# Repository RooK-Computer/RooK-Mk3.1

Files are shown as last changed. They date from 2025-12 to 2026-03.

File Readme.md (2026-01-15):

# RooK Mk3.1

RooK is a retro gaming console based on the Raspberry PI CM4/CM5. It has all the peripherials you need to be used as an old (modernish) console:

* HDMI for audio and video out.
* Barrel jack for 5V power input, because we love the simplicity of barrel jacks.
* an audio jack for, well... speakers!
* 4 USB ports for up to 4 modern gamepads.
* A cartridge slot!
* 3 Buttons to shut RooK down, exit the game and restart the game.

## How it all works

It's quite simple: instead of having an onboard SD card, the SD cards are installed onto separate PCBs for the cartridges. Once you put a cartridge in, RooK powers up and boots off the SD card in the cartridge.

Of course, unwrapping the SD cards can be tedious, so we built a cartridge reader.

It works out of the box with retropie, except for the three buttons. In this repository you find the software needed to enable those buttons. It's best done immediately after installing retropie, before you customize your setup.

## In this repository

There are 3 folders:

* software contains the sources for the .deb file to easily install overwatch and it's configuration. You'll find the .dep file in there as well, if you don't want to build it yourself. The source is compressed, as we have to ensure ownership and file privileges. Something git tends to ignore ;)
* PCBs contains all the designs for the PCBs involved: 
    * Cartridge - the PCB for cartridges
    * CartridgeReader - should be self-explanatory
    * KeyswitchCarrier - holds the switches for the three keys
    * Mainboard - the biggest of them.
    * Parts and CM4-Files are referenced in the aforementioned design files
* STLs contain the STL files for the case and the cartridge. You'll find our FreeCAD designs in there as well.

## I wanna build one!

Well for now, you have to produce and order the parts yourself. We're working on this. Stay tuned and keep an eye out at [rook.computer](https://rook.computer).

There is a building guide in the wiki.

## License

Unless noted otherwise this work is licensed under Creative Commons Attribution Share Alike 4.0 International.

`SPDX-License-Identifier:  CC-BY-SA-4.0`

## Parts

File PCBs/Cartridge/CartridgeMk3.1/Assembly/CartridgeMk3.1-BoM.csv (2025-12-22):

Id | Designator | Footprint | Quantity | Designation | Supplier and ref
2 | R1,R3,R5,R2,R4 | R_0201_0603Metric | 5 | 10k
3 | J2 | SDCARD_MOLEX_503398-1892 | 1 | Micro_SD_Card

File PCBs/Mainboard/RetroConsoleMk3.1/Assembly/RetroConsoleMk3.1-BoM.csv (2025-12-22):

Id | Designator | Footprint | Quantity | Designation | Supplier and ref
1 | R13,R12,R15,R11,R14,R16 | R_0201_0603Metric | 6 | 33
3 | C3 | C_0201_0603Metric | 1 | 10nF
4 | J7,J5,J6,J3 | USB_A_Molex_67643_Horizontal | 4 | USB_A | https://www.molex.com/en-us/products/part-detail/676432911
5 | C7,C5 | C_1206_3216Metric | 2 | 47uF
6 | J10 | SJ335083BTR | 1 | SJ3-35083B-TR | https://www.mouser.de/ProductDetail/Same-Sky/SJ3-35083B-TR?qs=IKkN%2F947nfDjNSxAQdYIVA%3D%3D
7 | J16,J15 | DF40C100DS04V51 | 2 | DF40C100DS04V51 | https://www.hirose.com/product/p/CL0684-4033-4-51?lang=en#
8 | J8 | PJ114AHSMTTR | 1 | PJ-114AH-SMT-TR | https://www.mouser.de/ProductDetail/Same-Sky/PJ-114AH-SMT-TR
9 | R7,R4 | R_0201_0603Metric | 2 | 220
10 | Y1 | 830108208209 | 1 | 830108208209 | https://www.mouser.de/ProductDetail/Wurth-Elektronik/830108208209?qs=hWgE7mdIu5Qfk68EXTEoAw%3D%3D
11 | R1 | R_0201_0603Metric | 1 | 1k
13 | R5,R8 | R_0201_0603Metric | 2 | 100
14 | IC2 | SOT65P210X110-6N | 1 | NC7WZ16P6X | https://www.mouser.de/ProductDetail/onsemi-Fairchild/NC7WZ16P6X?qs=yRUxxYa83cgjitXtxHB4eA%3D%3D
15 | R6,R9 | R_0201_0603Metric | 2 | 1.8k
17 | D1 | LED_0201_0603Metric | 1 | GREEN
18 | C6,C4 | C_0201_0603Metric | 2 | 100nF
20 | R10 | R_0201_0603Metric | 1 | 10k
21 | C1,C2 | C_0201_0603Metric | 2 | 14pF
23 | J9 | 18710581 | 1 | 1871058-1 | https://www.mouser.de/ProductDetail/TE-Connectivity/1871058-1?qs=%252BoxYCnKeKt%252BrW4wNNMzC1A%3D%3D
24 | J4 | HDMI_A_Molex_208658-1001_Horizontal | 1 | HDMI_A_1.4
25 | Q1 | IRF2804STRLPBF | 1 | IRLZ34NSTRLPBF | https://www.mouser.de/ProductDetail/Infineon-Technologies/IRLZ34NSTRLPBF?qs=9%252BKlkBgLFf3%2F7oYCM5eA2g%3D%3D
26 | J14 | JST_PH_B4B-PH-K_1x04_P2.00mm_Vertical | 1 | Keys
28 | J1 | JST_SH_BM04B-SRSS-TB_1x04-1MP_P1.00mm_Vertical | 1 | Conn_01x04_Socket
29 | R2 | R_0201_0603Metric | 1 | 100k
30 | R3 | R_0201_0603Metric | 1 | 12k (+/- 1%)
31 | IC1 | QFN50P600X600X100-37N-D | 1 | USB2514B_M2 | https://www.mouser.de/ProductDetail/Microchip-Technology/USB2514B-M2?qs=uus7iwvxYD9zlzrAre8ynw%3D%3D

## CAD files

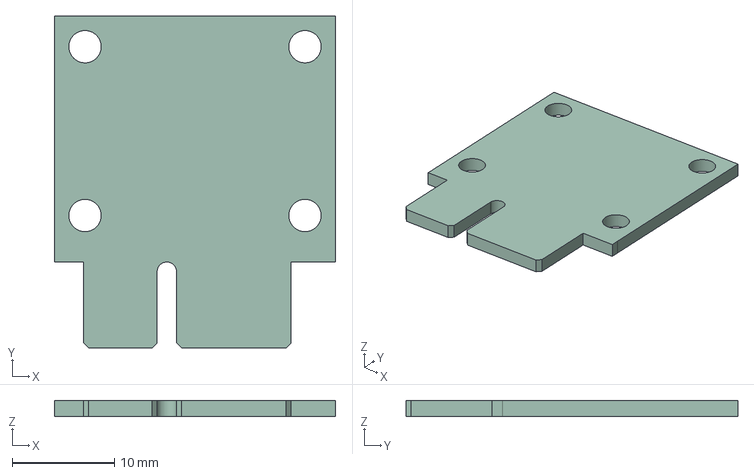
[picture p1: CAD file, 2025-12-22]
PCBs/Cartridge/CartridgeMk3.1/CartridgeMk1_simple.step
27.5 x 32.5 x 1.60 mm

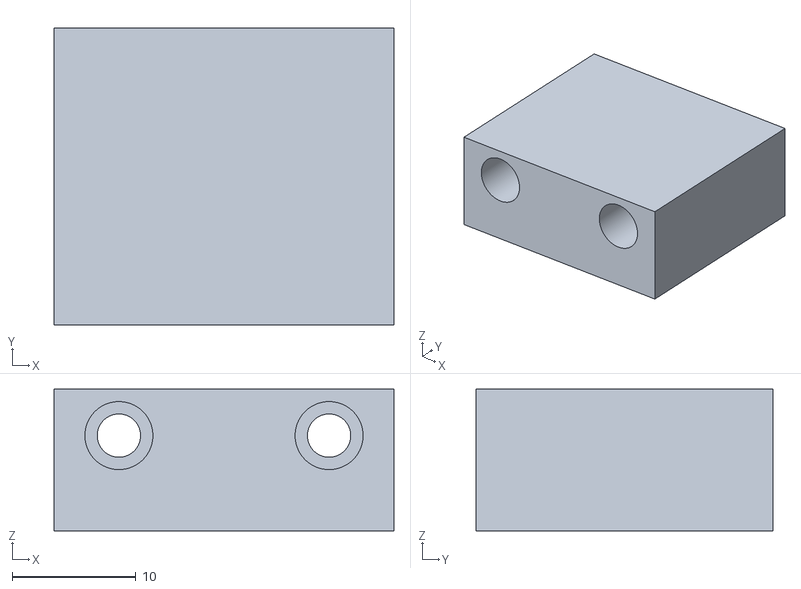
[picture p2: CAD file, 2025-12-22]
STLs/LegoInspiredCase_by_Konnexus_Mk1/CartridgeMk2-STLs/CartridgeMk3-FrontSide.stl
27.5 x 24.0 x 11.5

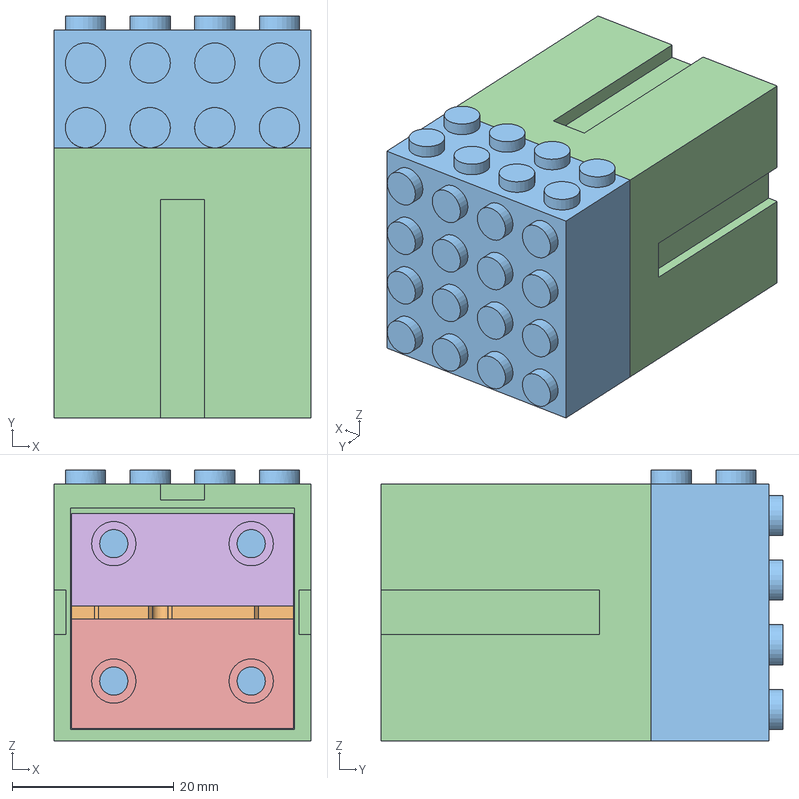
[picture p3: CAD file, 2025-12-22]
STLs/LegoInspiredCase_by_Konnexus_Mk1/CartridgeMk3.FCStd
31.8 x 49.7 x 33.5 mm
CartridgeMk1_PCB
TopPanel
Housing
BackSide
FrontSide

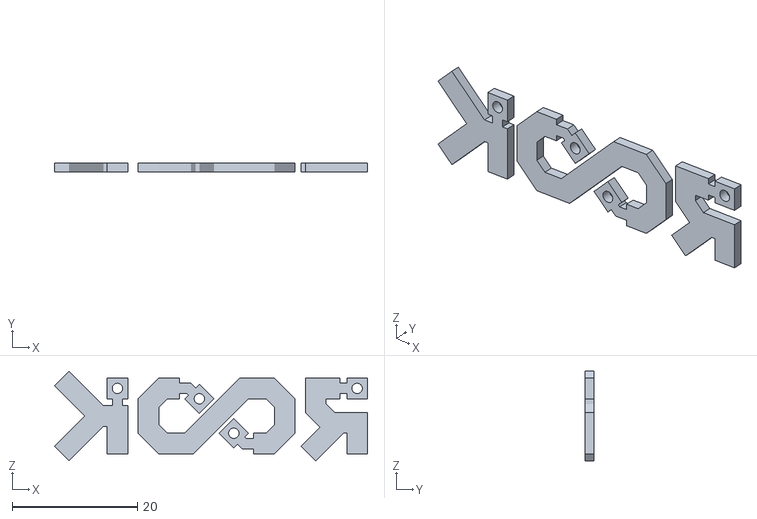
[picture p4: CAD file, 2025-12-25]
STLs/LegoInspiredCase_by_Konnexus_Mk1/Case-STLs/BackPanel_Inlay.stl
50.0 x 1.40 x 14.3

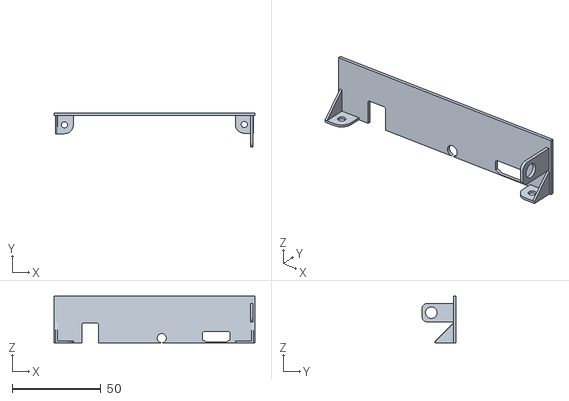
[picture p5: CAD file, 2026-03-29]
STLs/WifiAntennaMod/BackPanel_internal_antenna.stl
113.2 x 19.2 x 26.2

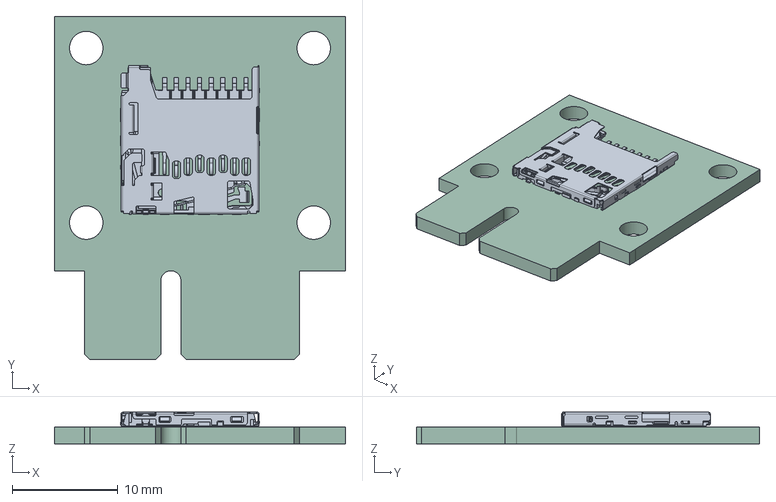
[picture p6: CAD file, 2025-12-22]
PCBs/Cartridge/CartridgeMk3.1/CartridgeMk3.1.step
27.5 x 32.5 x 2.98 mm
CartridgeMk1_PCB

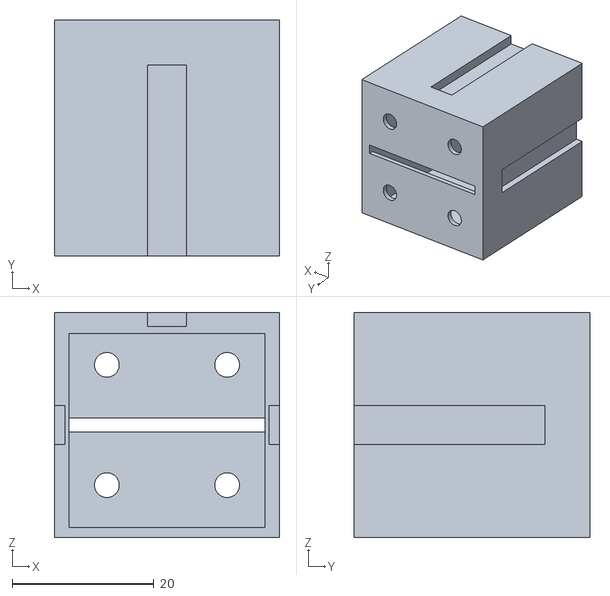
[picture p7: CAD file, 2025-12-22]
STLs/LegoInspiredCase_by_Konnexus_Mk1/CartridgeMk2-STLs/CartridgeMk3-Housing.stl
31.8 x 33.4 x 31.8

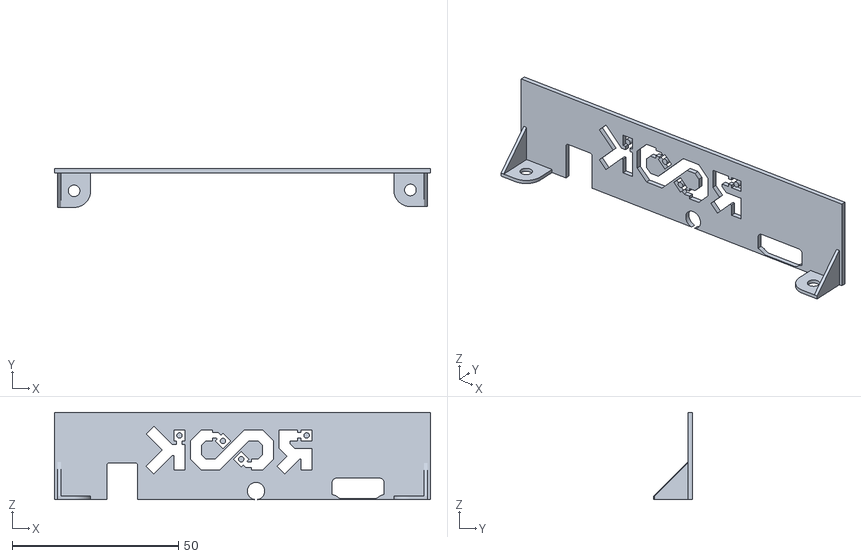
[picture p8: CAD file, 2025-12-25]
STLs/LegoInspiredCase_by_Konnexus_Mk1/Case-STLs/BackPanel.stl
113.2 x 11.7 x 26.2

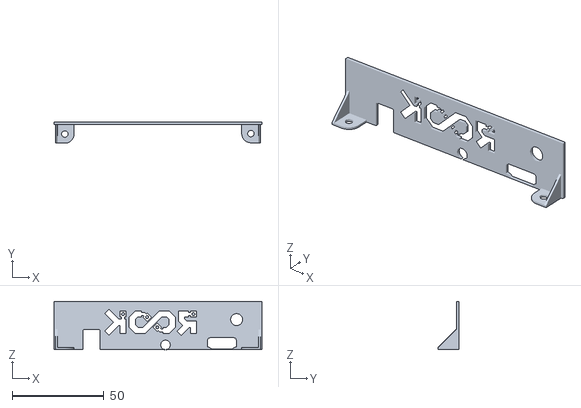
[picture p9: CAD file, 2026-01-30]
STLs/WifiAntennaMod/BackPanel.stl
113.2 x 11.7 x 26.2

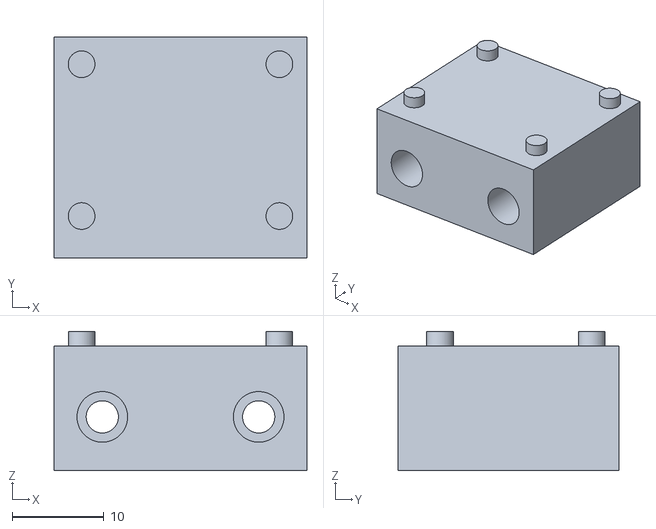
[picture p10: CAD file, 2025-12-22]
STLs/LegoInspiredCase_by_Konnexus_Mk1/CartridgeMk2-STLs/CartridgeMk3-BackSide.stl
27.5 x 24.0 x 15.2

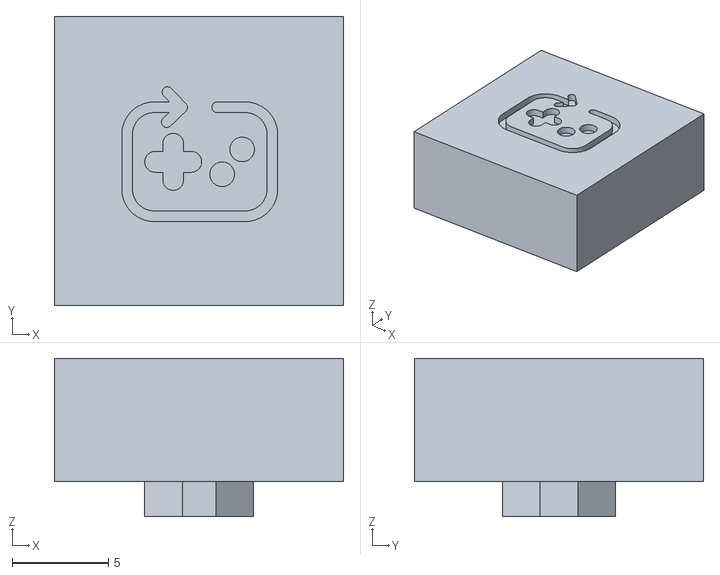
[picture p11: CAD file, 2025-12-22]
STLs/LegoInspiredCase_by_Konnexus_Mk1/Case-STLs/ResetButton_fat.stl
15.0 x 15.0 x 8.21

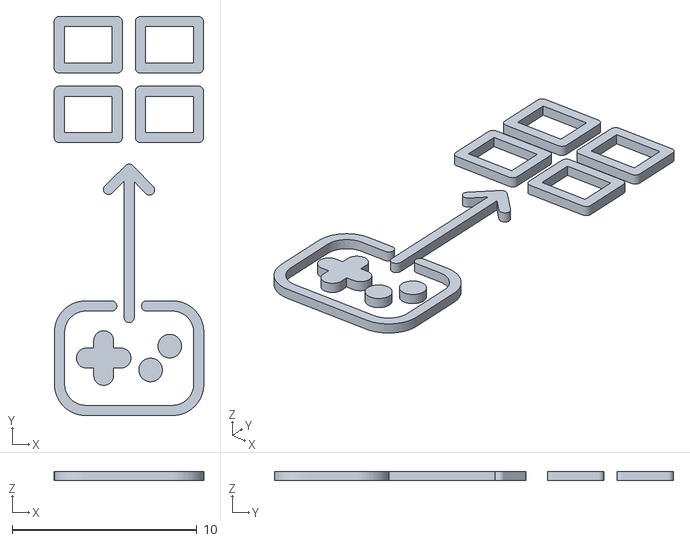
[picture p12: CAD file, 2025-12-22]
STLs/LegoInspiredCase_by_Konnexus_Mk1/Case-STLs/QuitButton_fat_print.stl
8.11 x 21.6 x 0.5

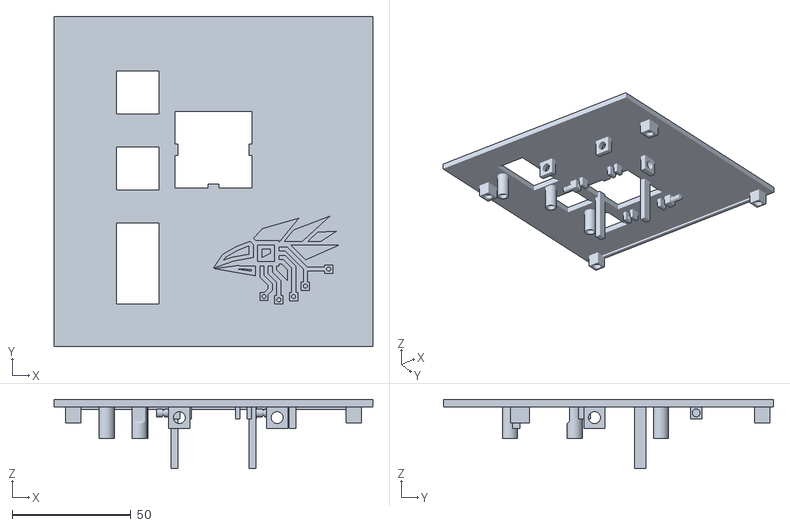
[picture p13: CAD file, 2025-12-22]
STLs/LegoInspiredCase_by_Konnexus_Mk1/Case-STLs/Cover.stl
134.2 x 139.0 x 29.2

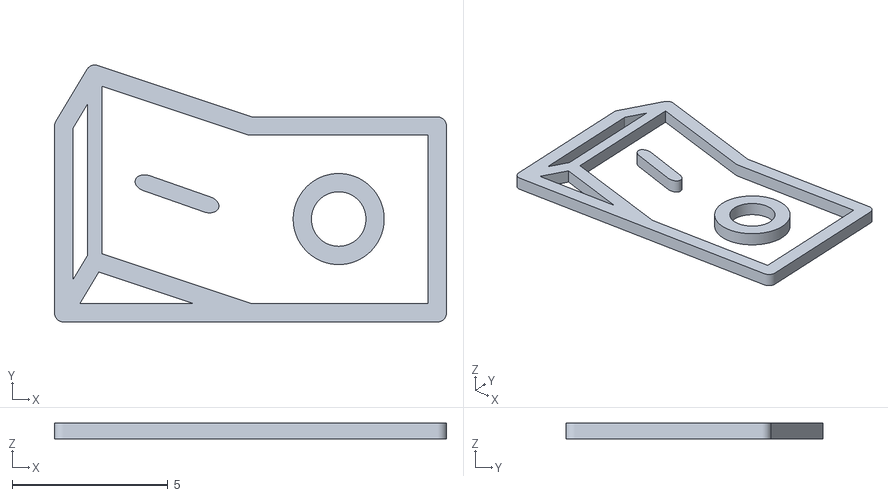
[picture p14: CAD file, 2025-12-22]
STLs/LegoInspiredCase_by_Konnexus_Mk1/Case-STLs/ShutdownButton_print.stl
12.6 x 8.24 x 0.5

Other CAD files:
STLs/LegoInspiredCase_by_Konnexus_Mk1/Case-STLs/ShutdownButton.stl
STLs/LegoInspiredCase_by_Konnexus_Mk1/Case-STLs/SlotCover.stl
STLs/LegoInspiredCase_by_Konnexus_Mk1/Case-STLs/ShutdownButton_border.stl
STLs/LegoInspiredCase_by_Konnexus_Mk1/Case-STLs/QuitButton_fat.stl
STLs/LegoInspiredCase_by_Konnexus_Mk1/Case-STLs/Base.stl
STLs/LegoInspiredCase_by_Konnexus_Mk1/Case-STLs/Pillars.stl
STLs/LegoInspiredCase_by_Konnexus_Mk1/Case-STLs/QuitButton_fat_border.stl
STLs/LegoInspiredCase_by_Konnexus_Mk1/Case-STLs/ResetButton_fat_border.stl
STLs/LegoInspiredCase_by_Konnexus_Mk1/Case-STLs/ResetButton_fat_print.stl

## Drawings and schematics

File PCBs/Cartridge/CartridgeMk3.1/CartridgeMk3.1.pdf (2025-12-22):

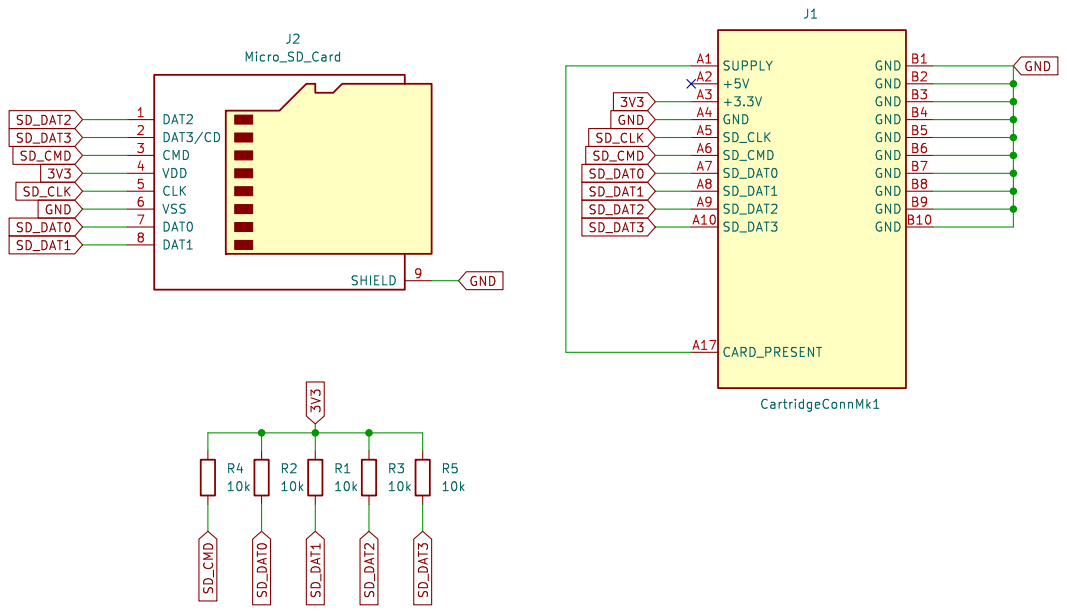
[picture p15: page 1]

Id: 1/1 Title: File: CartridgeMk3.kicad_sch Sheet: /

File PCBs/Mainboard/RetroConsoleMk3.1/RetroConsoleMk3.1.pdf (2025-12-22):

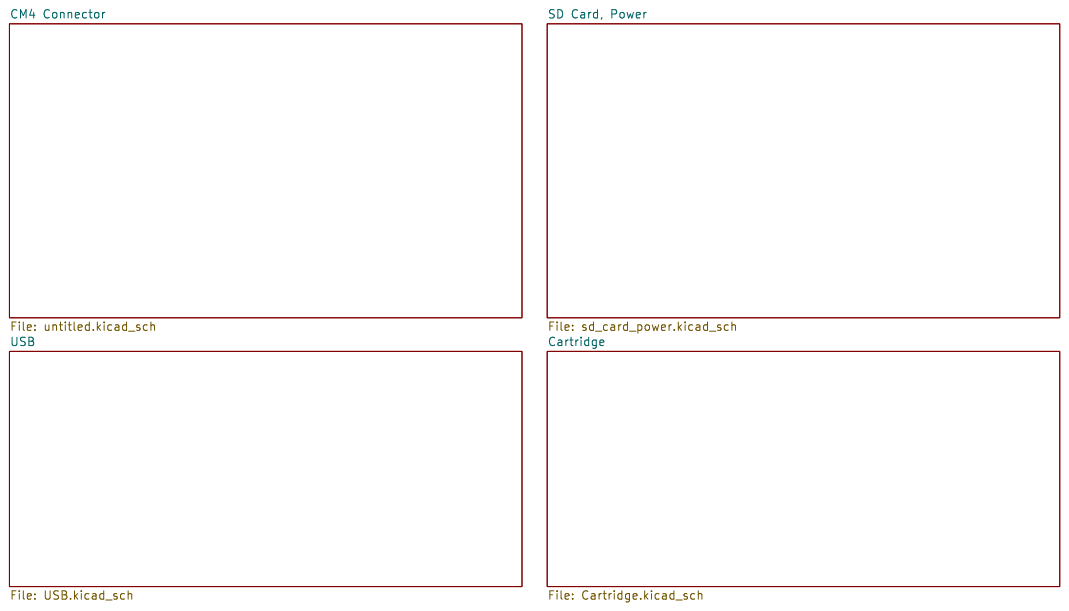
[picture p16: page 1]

File: USB.kicad_sch CM4 Connector File: untitled.kicad_sch

SD Card, Power File: sd_card_power.kicad_sch USB

Id: 1/5 Title: File: RetroConsoleMk3.kicad_sch Sheet: /

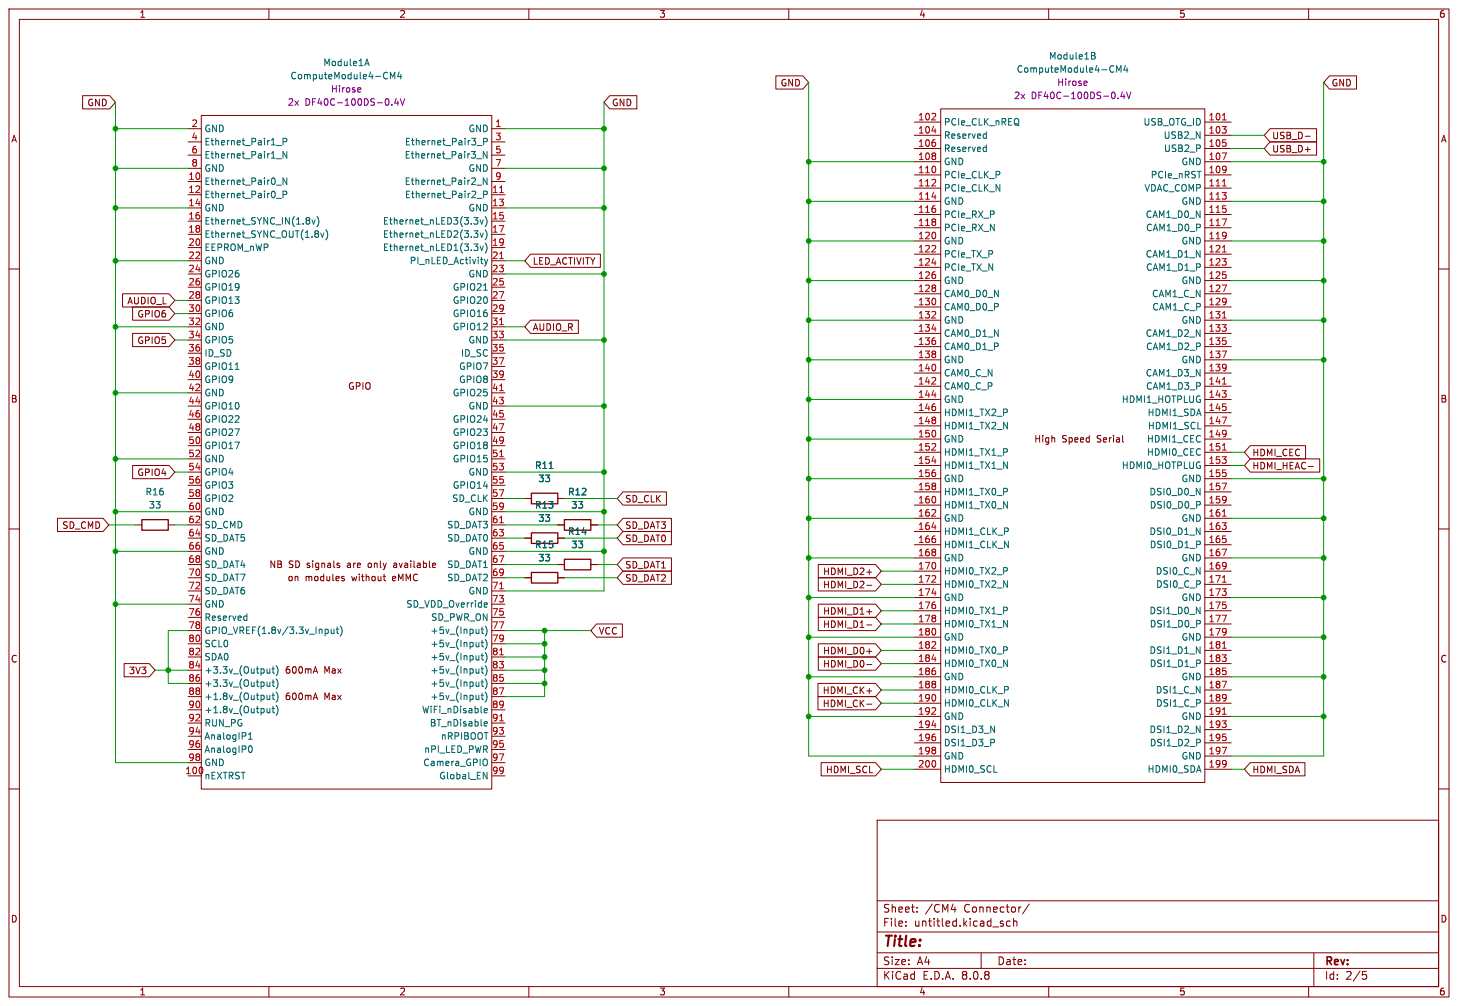
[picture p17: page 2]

600mA Max 600mA Max NB SD signals are only available

Id: 2/5 Title: File: untitled.kicad_sch Sheet: /CM4 Connector/

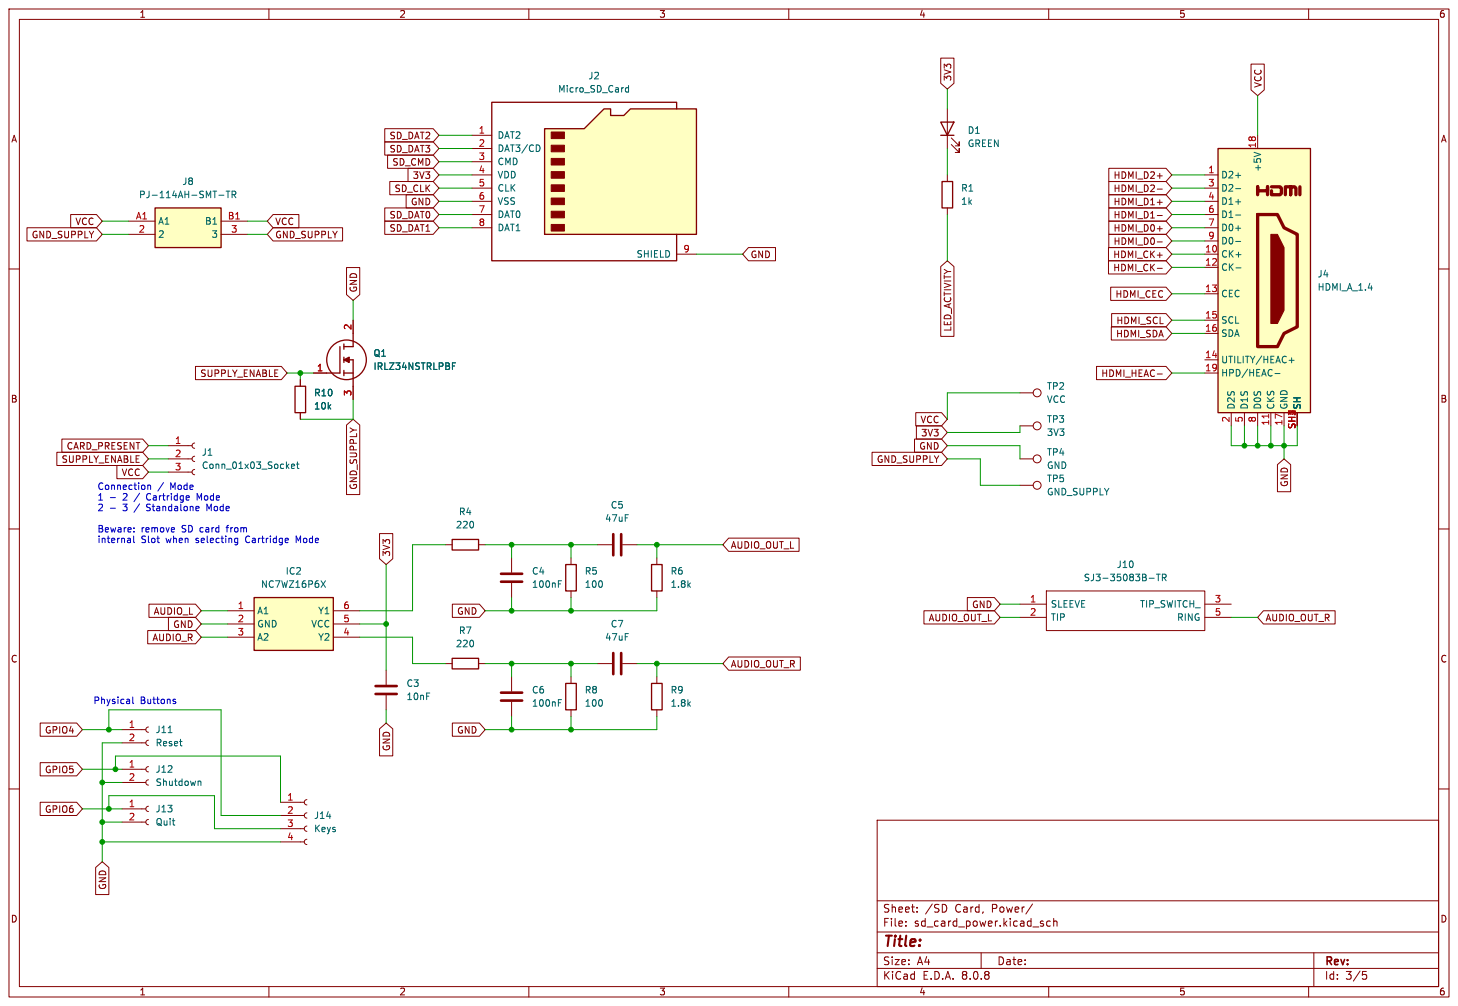
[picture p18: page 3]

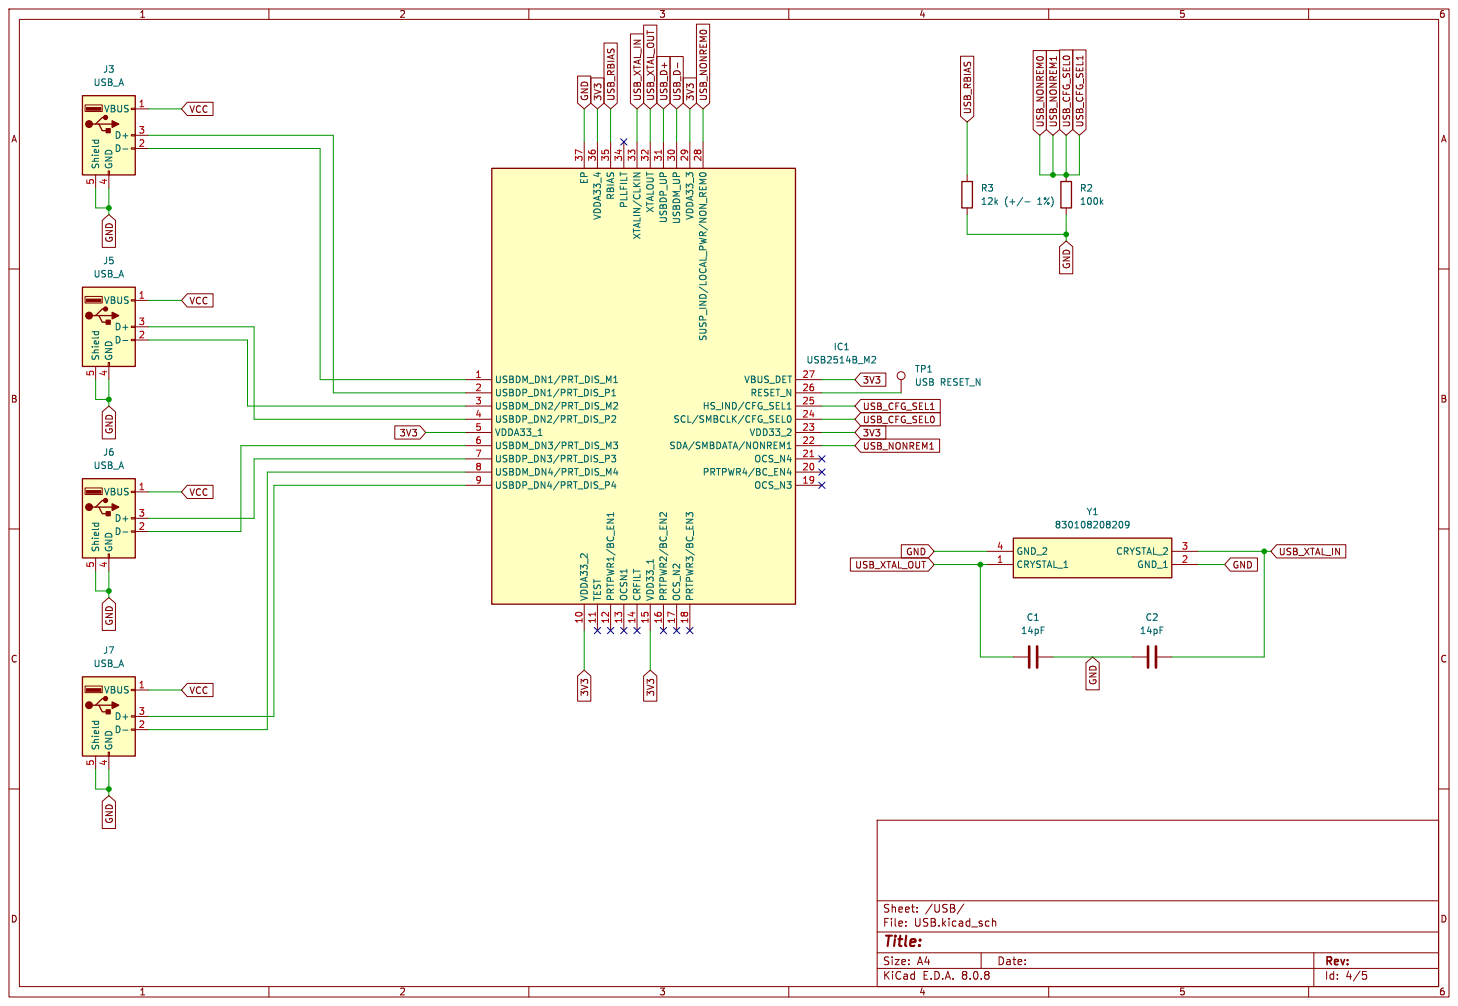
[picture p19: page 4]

Id: 4/5 Title: File: USB.kicad_sch Sheet: /USB/

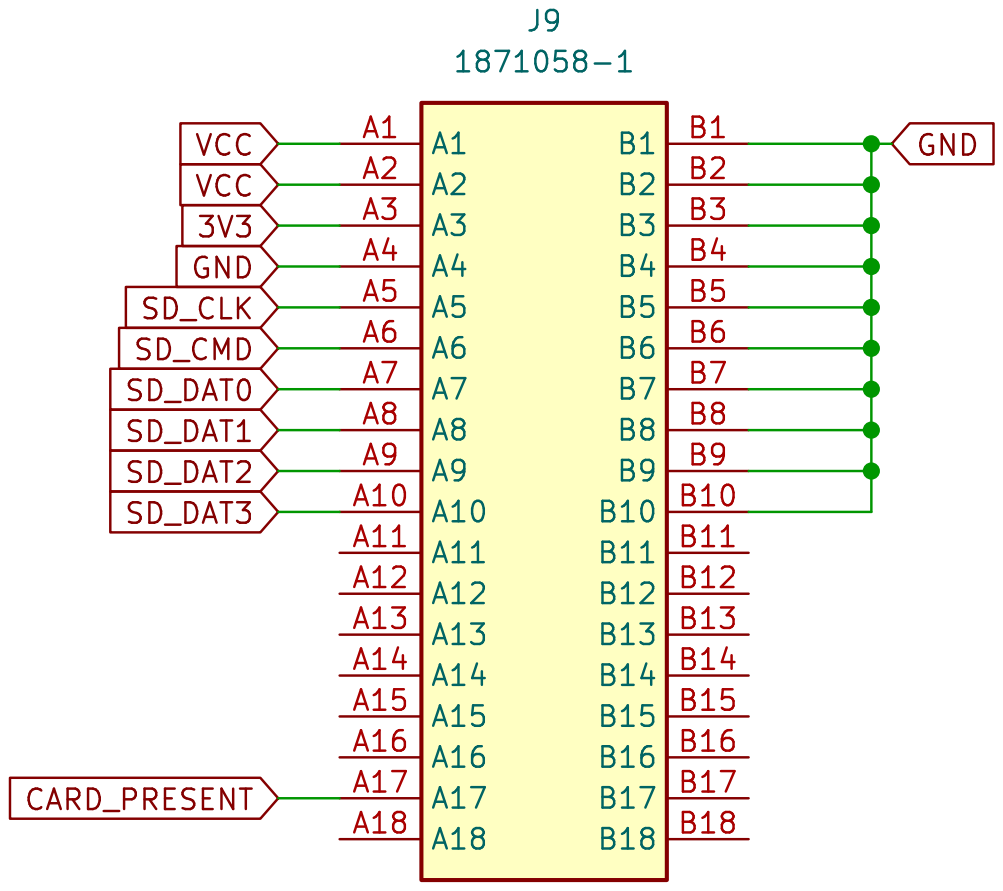
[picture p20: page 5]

Id: 5/5 Title: File: Cartridge.kicad_sch Sheet: /Cartridge/

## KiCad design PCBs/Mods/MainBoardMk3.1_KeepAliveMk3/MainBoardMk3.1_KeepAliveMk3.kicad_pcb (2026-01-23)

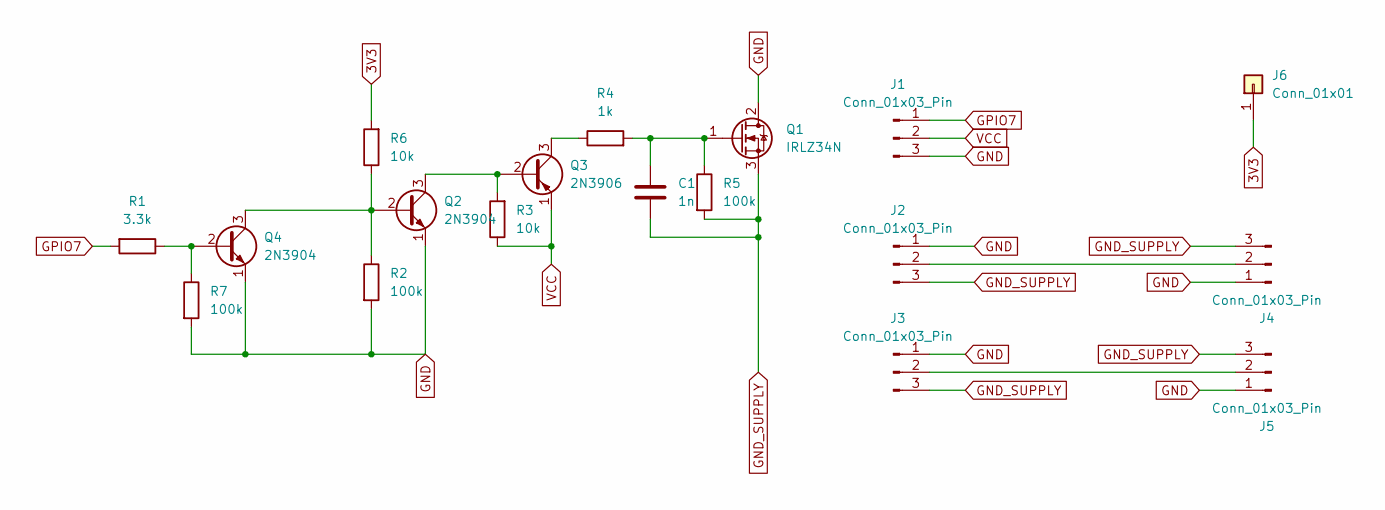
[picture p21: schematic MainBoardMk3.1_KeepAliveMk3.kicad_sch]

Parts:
C1: 1n; C_Disc_D5.0mm_W2.5mm_P2.50mm
J1, J2, J3: Conn_01x03_Pin; PinSocket_1x03_P2.54mm_Vertical
J4, J5: Conn_01x03_Pin; PinHeader_1x03_P2.54mm_Vertical
J6: Conn_01x01; SolderWire-0.5sqmm_1x01_D0.9mm_OD2.1mm
Q1: IRLZ34N; TO-220-3_Horizontal_TabDown
Q2, Q4: 2N3904; TO-92_HandSolder
Q3: 2N3906; TO-92_HandSolder
R1: 3.3k; R_Axial_DIN0207_L6.3mm_D2.5mm_P7.62mm_Horizontal
R2, R5, R7: 100k; R_Axial_DIN0207_L6.3mm_D2.5mm_P7.62mm_Horizontal
R3, R6: 10k; R_Axial_DIN0207_L6.3mm_D2.5mm_P7.62mm_Horizontal
R4: 1k; R_Axial_DIN0207_L6.3mm_D2.5mm_P7.62mm_Horizontal

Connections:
3V3: J6.1, R6.2
GND: J1.3, J2.1, J3.1, J4.1, J5.1, Q1.2 (D), Q2.1 (E), Q4.1 (E), R2.2, R7.2
GND_SUPPLY: C1.2, J2.3, J3.3, J4.3, J5.3, Q1.3 (S), R5.2
GPIO7: J1.1, R1.2
unnamed: J2.2, J4.2
unnamed: J3.2, J5.2
unnamed: C1.1, Q1.1 (G), R4.2, R5.1
unnamed: Q2.2 (B), Q4.3 (C), R2.1, R6.1
unnamed: Q2.3 (C), Q3.2 (B), R3.2
unnamed: Q3.3 (C), R4.1
unnamed: Q4.2 (B), R1.1, R7.1
VCC: J1.2, Q3.1 (E), R3.1

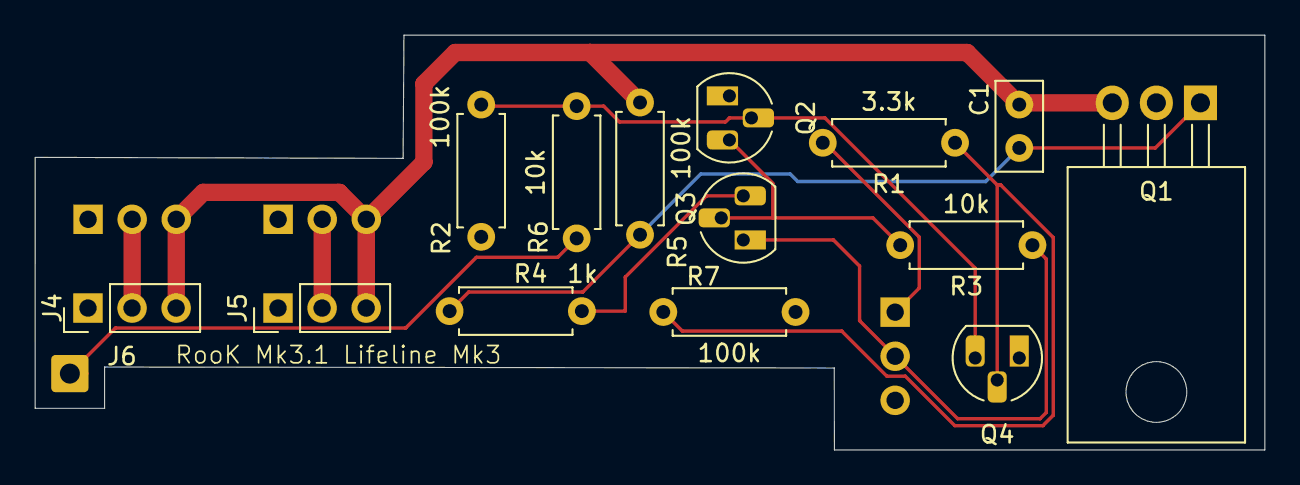
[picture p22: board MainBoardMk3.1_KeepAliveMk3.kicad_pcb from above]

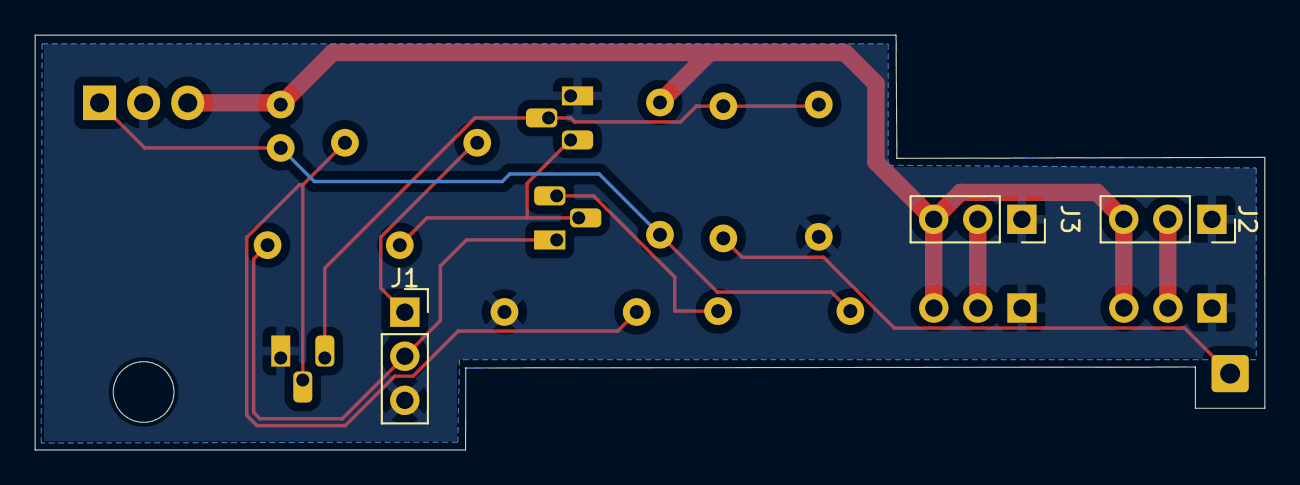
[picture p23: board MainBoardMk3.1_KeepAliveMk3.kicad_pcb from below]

Board: 2 copper layers, 70.8 x 23.9 mm, 18 parts (3 on the bottom side), 12 nets.

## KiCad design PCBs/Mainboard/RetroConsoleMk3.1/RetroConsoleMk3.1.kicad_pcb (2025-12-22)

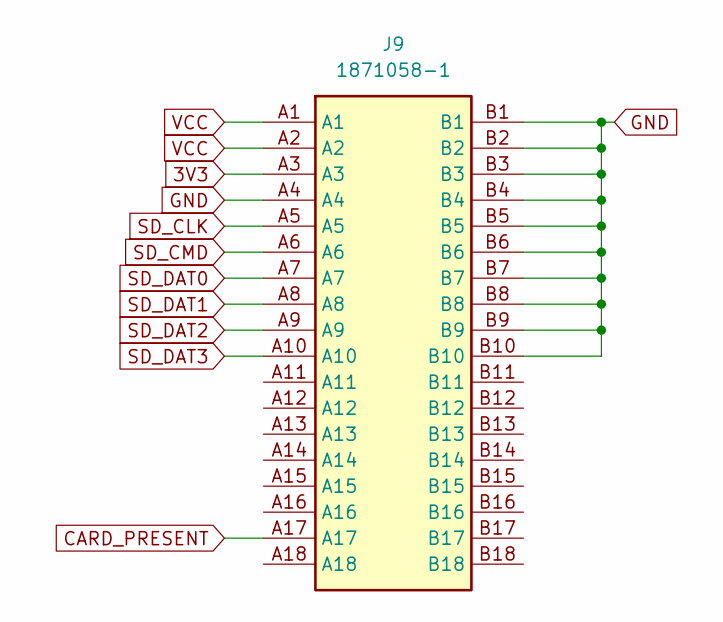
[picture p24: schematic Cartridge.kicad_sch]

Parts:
J9: 1871058-1; 18710581; Manufacturer_Part_Number 1871058-1; Mouser Part Number 571-1871058-1

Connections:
3V3: J9.A3; also elsewhere on the board
CARD_PRESENT: J9.A17; also elsewhere on the board
GND: J9.A4, J9.B1, J9.B2, J9.B3, J9.B4, J9.B5, J9.B6, J9.B7, J9.B8, J9.B9, J9.B10; also elsewhere on the board
SD_CLK: J9.A5; also elsewhere on the board
SD_CMD: J9.A6; also elsewhere on the board
SD_DAT0: J9.A7; also elsewhere on the board
SD_DAT1: J9.A8; also elsewhere on the board
SD_DAT2: J9.A9; also elsewhere on the board
SD_DAT3: J9.A10; also elsewhere on the board
VCC: J9.A1, J9.A2; also elsewhere on the board

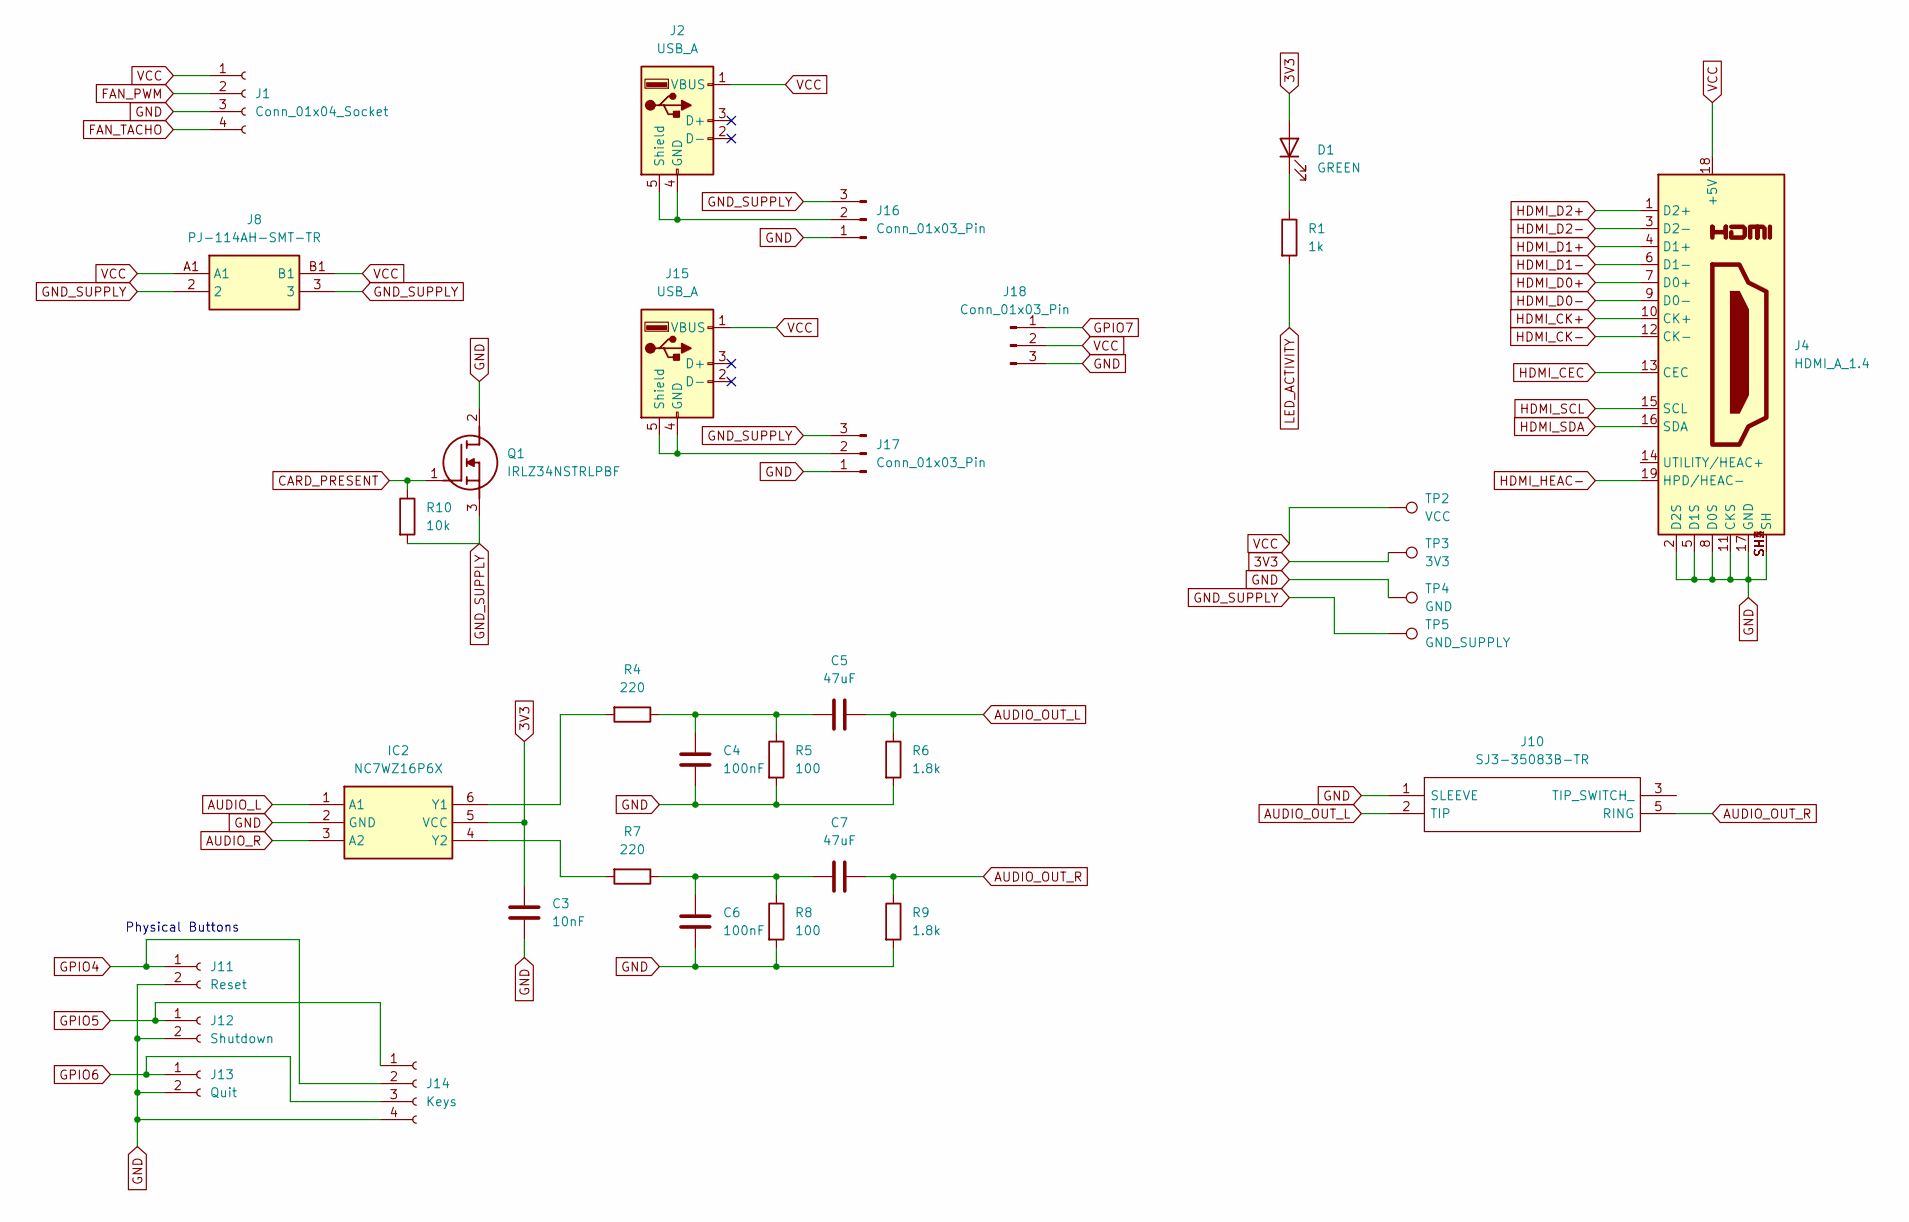
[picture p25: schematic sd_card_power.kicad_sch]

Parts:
C3: 10nF; C_0201_0603Metric
C4, C6: 100nF; C_0201_0603Metric
C5, C7: 47uF; C_1206_3216Metric
D1: GREEN; LED_0201_0603Metric
IC2: NC7WZ16P6X; SOT65P210X110-6N; Manufacturer_Part_Number NC7WZ16P6X; Mouser Part Number 512-NC7WZ16P6X
J1: Conn_01x04_Socket; JST_SH_BM04B-SRSS-TB_1x04-1MP_P1.00mm_Vertical
J2, J15: USB_A; USB_A_Wuerth_614004134726_Horizontal
J4: HDMI_A_1.4; HDMI_A_Molex_208658-1001_Horizontal
J8: PJ-114AH-SMT-TR; PJ114AHSMTTR; Manufacturer_Part_Number PJ-114AH-SMT-TR; Mouser Part Number 179-PJ-114AH-SMT-TR
J10: SJ3-35083B-TR; SJ335083BTR; Manufacturer_Part_Number SJ3-35083B-TR; Mouser Part Number 179-SJ3-35083B-TR
J11: Reset; JST_PH_B2B-PH-K_1x02_P2.00mm_Vertical
J12: Shutdown; JST_PH_B2B-PH-K_1x02_P2.00mm_Vertical
J13: Quit; JST_PH_B2B-PH-K_1x02_P2.00mm_Vertical
J14: Keys; JST_PH_B4B-PH-K_1x04_P2.00mm_Vertical
J16, J17, J18: Conn_01x03_Pin; PinHeader_1x03_P2.54mm_Vertical
Q1: IRLZ34NSTRLPBF; IRF2804STRLPBF; Manufacturer_Part_Number IRLZ34NSTRLPBF; Mouser Part Number 942-IRLZ34NSTRLPBF
R1: 1k; R_0201_0603Metric
R4, R7: 220; R_0201_0603Metric
R5, R8: 100; R_0201_0603Metric
R6, R9: 1.8k; R_0201_0603Metric
R10: 10k; R_0201_0603Metric
TP2: VCC; TestPoint_Pad_D3.0mm
TP3: 3V3; TestPoint_Pad_D3.0mm
TP4: GND; TestPoint_Pad_D3.0mm
TP5: GND_SUPPLY; TestPoint_Pad_D3.0mm

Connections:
3V3: C3.1, D1.2 (A), IC2.5 (VCC), TP3.1; also elsewhere on the board
AUDIO_L: IC2.1 (A1); also elsewhere on the board
AUDIO_OUT_L: C5.1, J10.2 (TIP), R6.1
AUDIO_OUT_R: C7.1, J10.5 (RING), R9.1
AUDIO_R: IC2.3 (A2); also elsewhere on the board
CARD_PRESENT: Q1.1 (G), R10.1; also elsewhere on the board
FAN_PWM: J1.2; also elsewhere on the board
FAN_TACHO: J1.4; also elsewhere on the board
GND: C3.2, C4.2, C6.2, IC2.2 (GND), J1.3, J4.2 (D2S), J4.5 (D1S), J4.8 (D0S), J4.11 (CKS), J4.17 (GND), J4.SH1 (SH), J4.SH2 (SH), J4.SH3 (SH), J4.SH4 (SH), J10.1 (SLEEVE), J11.2, J12.2, J13.2, J14.4, J16.1, J17.1, J18.3, Q1.2 (D), R5.2, R6.2, R8.2, R9.2, TP4.1; also elsewhere on the board
GND_SUPPLY: J8.2, J8.3, J16.3, J17.3, Q1.3 (S), R10.2, TP5.1
GPIO4: J11.1, J14.2; also elsewhere on the board
GPIO5: J12.1, J14.1; also elsewhere on the board
GPIO6: J13.1, J14.3; also elsewhere on the board
GPIO7: J18.1; also elsewhere on the board
HDMI_CEC: J4.13 (CEC); also elsewhere on the board
HDMI_CK+: J4.10 (CK+); also elsewhere on the board
HDMI_CK-: J4.12 (CK-); also elsewhere on the board
HDMI_D0+: J4.7 (D0+); also elsewhere on the board
HDMI_D0-: J4.9 (D0-); also elsewhere on the board
HDMI_D1+: J4.4 (D1+); also elsewhere on the board
HDMI_D1-: J4.6 (D1-); also elsewhere on the board
HDMI_D2+: J4.1 (D2+); also elsewhere on the board
HDMI_D2-: J4.3 (D2-); also elsewhere on the board
HDMI_HEAC-: J4.19 (HPD/HEAC-); also elsewhere on the board
HDMI_SCL: J4.15 (SCL); also elsewhere on the board
HDMI_SDA: J4.16 (SDA); also elsewhere on the board
LED_ACTIVITY: R1.2; also elsewhere on the board
unnamed: C4.1, C5.2, R4.1, R5.1
unnamed: C6.1, C7.2, R7.1, R8.1
unnamed: D1.1 (K), R1.1
unnamed: IC2.6 (Y1), R4.2
unnamed: IC2.4 (Y2), R7.2
unnamed: J15.4 (GND), J15.5 (Shield), J17.2
unnamed: J2.4 (GND), J2.5 (Shield), J16.2
VCC: J1.1, J2.1 (VBUS), J4.18 (+5V), J8.A1, J8.B1, J15.1 (VBUS), J18.2, TP2.1; also elsewhere on the board

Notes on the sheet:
Physical Buttons

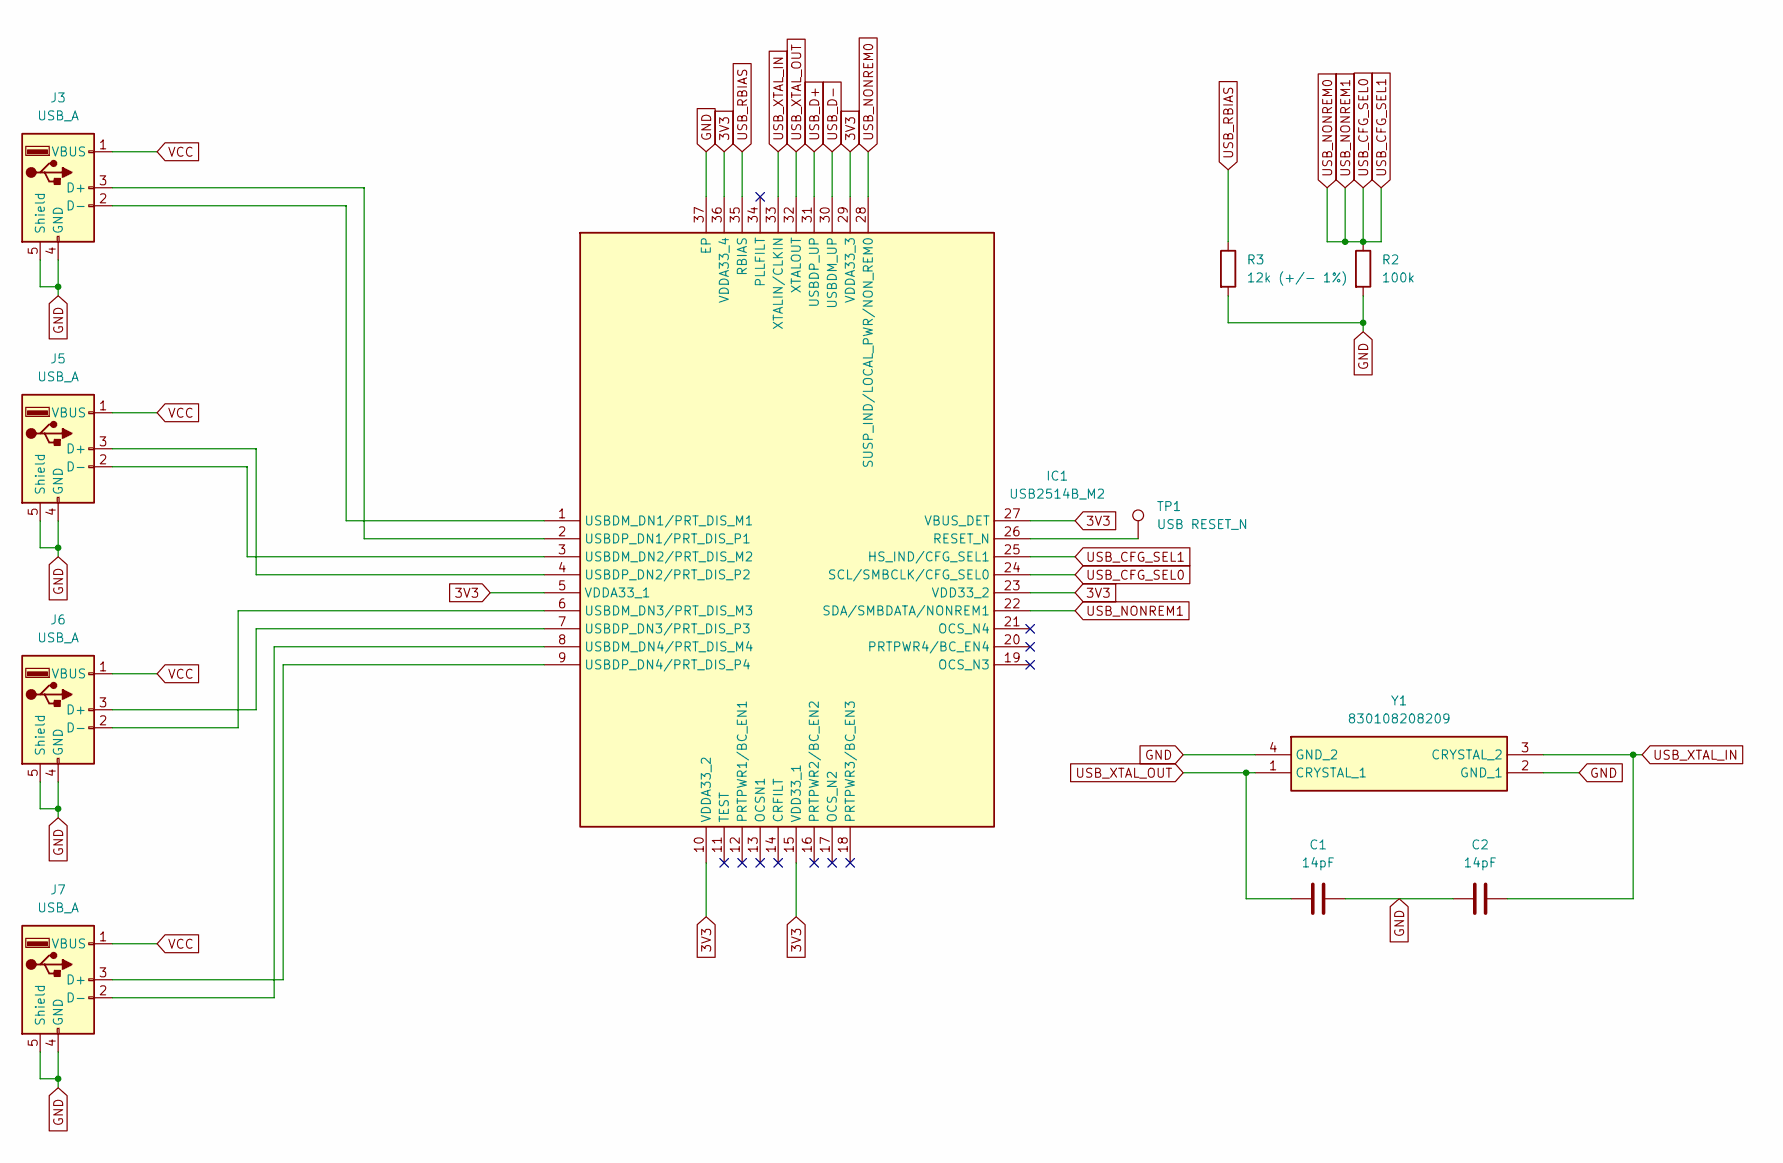
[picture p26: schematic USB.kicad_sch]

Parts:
C1, C2: 14pF; C_0201_0603Metric
IC1: USB2514B_M2; QFN50P600X600X100-37N-D; Manufacturer_Part_Number USB2514B/M2; Mouser Part Number 579-USB2514B/M2
J3, J5, J6, J7: USB_A; USB_A_Molex_67643_Horizontal
R2: 100k; R_0201_0603Metric
R3: 12k (+/- 1%); R_0201_0603Metric
TP1: USB RESET_N; TestPoint_Pad_D3.0mm
Y1: 830108208209; Manufacturer_Part_Number 830108208209; Mouser Part Number 710-830108208209

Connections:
3V3: IC1.5 (VDDA33_1), IC1.10 (VDDA33_2), IC1.15 (VDD33_1), IC1.23 (VDD33_2), IC1.27 (VBUS_DET), IC1.29 (VDDA33_3), IC1.36 (VDDA33_4); also elsewhere on the board
GND: C1.1, C2.2, IC1.37 (EP), J3.4 (GND), J3.5 (Shield), J5.4 (GND), J5.5 (Shield), J6.4 (GND), J6.5 (Shield), J7.4 (GND), J7.5 (Shield), R2.2, R3.2, Y1.2 (GND_1), Y1.4 (GND_2); also elsewhere on the board
unnamed: IC1.26 (RESET_N), TP1.1
unnamed: IC1.1 (USBDM_DN1/PRT_DIS_M1), J3.2 (D-)
unnamed: IC1.3 (USBDM_DN2/PRT_DIS_M2), J5.2 (D-)
unnamed: IC1.6 (USBDM_DN3/PRT_DIS_M3), J6.2 (D-)
unnamed: IC1.8 (USBDM_DN4/PRT_DIS_M4), J7.2 (D-)
unnamed: IC1.2 (USBDP_DN1/PRT_DIS_P1), J3.3 (D+)
unnamed: IC1.4 (USBDP_DN2/PRT_DIS_P2), J5.3 (D+)
unnamed: IC1.7 (USBDP_DN3/PRT_DIS_P3), J6.3 (D+)
unnamed: IC1.9 (USBDP_DN4/PRT_DIS_P4), J7.3 (D+)
USB_CFG_SEL0: IC1.22 (SDA/SMBDATA/NONREM1), IC1.24 (SCL/SMBCLK/CFG_SEL0), IC1.25 (HS_IND/CFG_SEL1), IC1.28 (SUSP_IND/LOCAL_PWR/NON_REM0), R2.1
USB_D+: IC1.31 (USBDP_UP); also elsewhere on the board
USB_D-: IC1.30 (USBDM_UP); also elsewhere on the board
USB_RBIAS: IC1.35 (RBIAS), R3.1
USB_XTAL_IN: C2.1, IC1.33 (XTALIN/CLKIN), Y1.3 (CRYSTAL_2)
USB_XTAL_OUT: C1.2, IC1.32 (XTALOUT), Y1.1 (CRYSTAL_1)
VCC: J3.1 (VBUS), J5.1 (VBUS), J6.1 (VBUS), J7.1 (VBUS); also elsewhere on the board

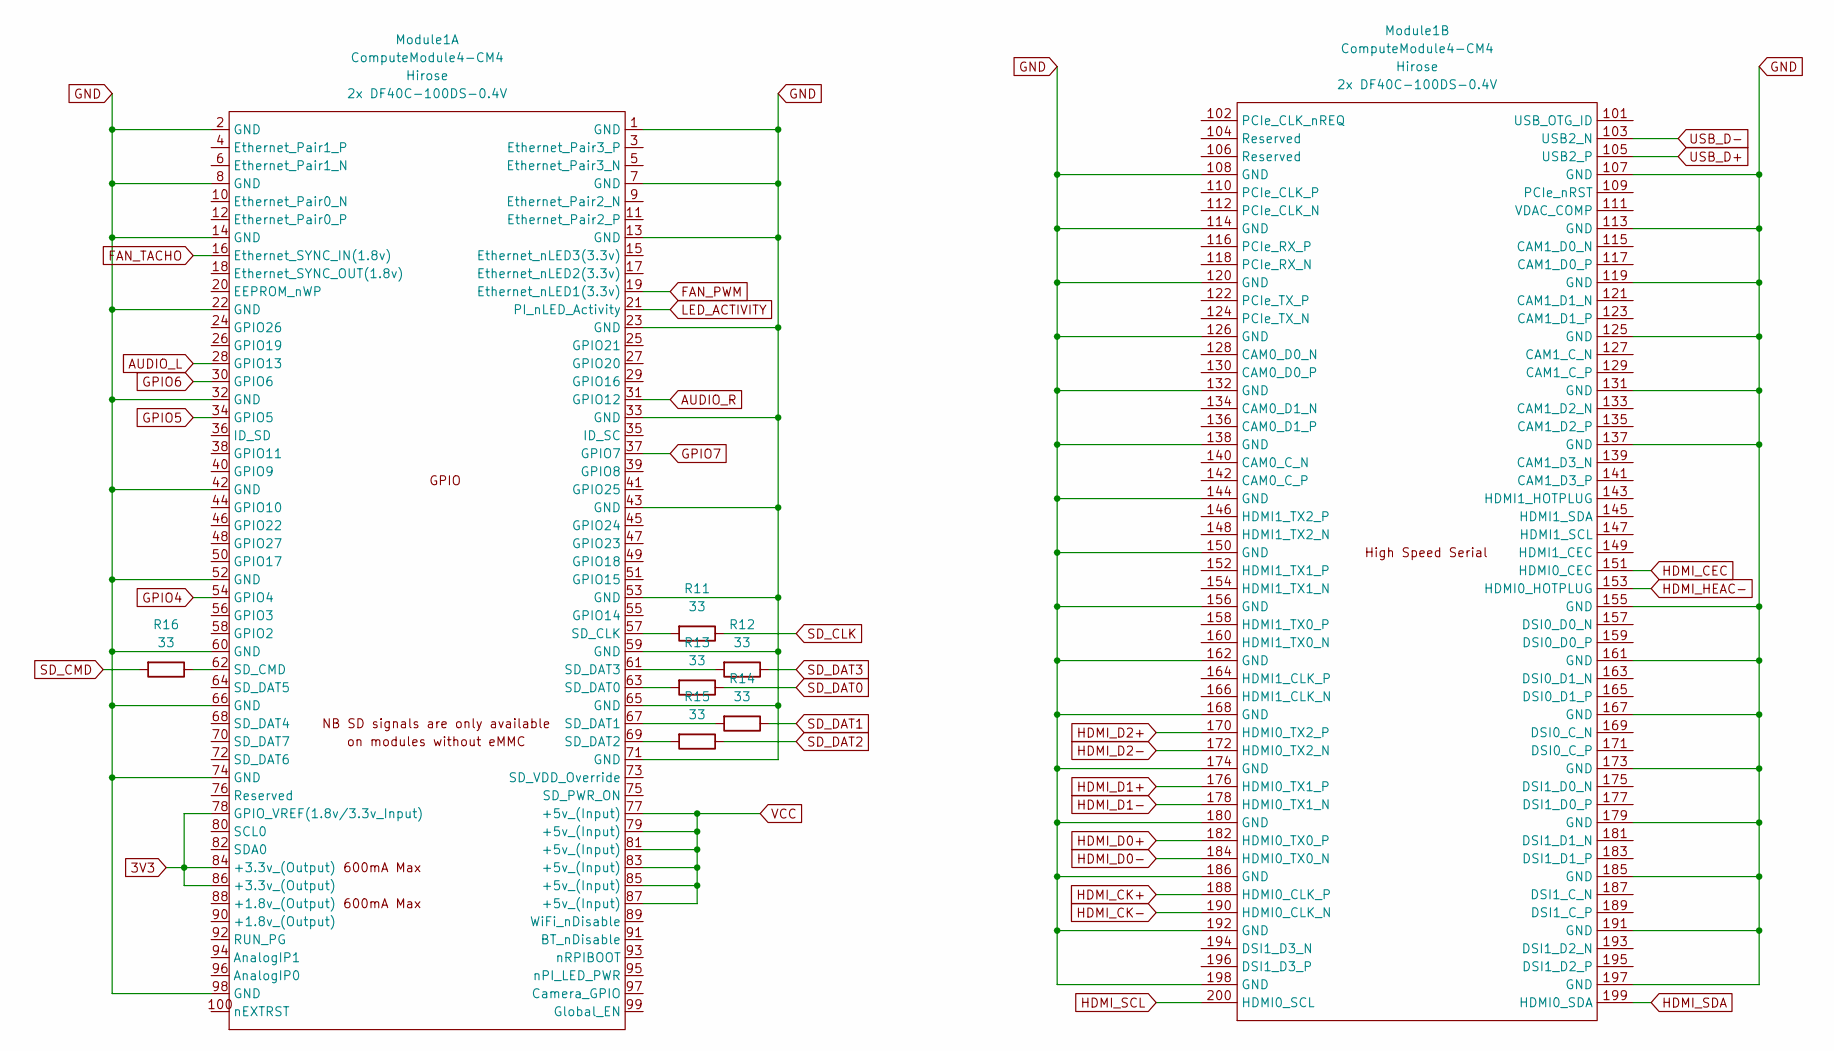
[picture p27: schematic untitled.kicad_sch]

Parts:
Module1: ComputeModule4-CM4; Raspberry-Pi-4-Compute-Module
R11, R12, R13, R14, R15, R16: 33; R_0201_0603Metric

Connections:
3V3: Module1.78 (GPIO_VREF(1.8v/3.3v_Input)), Module1.84 (+3.3v_(Output)), Module1.86 (+3.3v_(Output)); also elsewhere on the board
AUDIO_L: Module1.28 (GPIO13); also elsewhere on the board
AUDIO_R: Module1.31 (GPIO12); also elsewhere on the board
FAN_PWM: Module1.19 (Ethernet_nLED1(3.3v)); also elsewhere on the board
FAN_TACHO: Module1.16 (Ethernet_SYNC_IN(1.8v)); also elsewhere on the board
GND: Module1.1 (GND), Module1.2 (GND), Module1.7 (GND), Module1.8 (GND), Module1.13 (GND), Module1.14 (GND), Module1.22 (GND), Module1.23 (GND), Module1.32 (GND), Module1.33 (GND), Module1.42 (GND), Module1.43 (GND), Module1.52 (GND), Module1.53 (GND), Module1.59 (GND), Module1.60 (GND), Module1.65 (GND), Module1.66 (GND), Module1.71 (GND), Module1.74 (GND), Module1.98 (GND), Module1.107 (GND), Module1.108 (GND), Module1.113 (GND), Module1.114 (GND), Module1.119 (GND), Module1.120 (GND), Module1.125 (GND), Module1.126 (GND), Module1.131 (GND), Module1.132 (GND), Module1.137 (GND), Module1.138 (GND), Module1.144 (GND), Module1.150 (GND), Module1.155 (GND), Module1.156 (GND), Module1.161 (GND), Module1.162 (GND), Module1.167 (GND), Module1.168 (GND), Module1.173 (GND), Module1.174 (GND), Module1.179 (GND), Module1.180 (GND), Module1.185 (GND), Module1.186 (GND), Module1.191 (GND), Module1.192 (GND), Module1.197 (GND), Module1.198 (GND); also elsewhere on the board
GPIO4: Module1.54 (GPIO4); also elsewhere on the board
GPIO5: Module1.34 (GPIO5); also elsewhere on the board
GPIO6: Module1.30 (GPIO6); also elsewhere on the board
GPIO7: Module1.37 (GPIO7); also elsewhere on the board
HDMI_CEC: Module1.151 (HDMI0_CEC); also elsewhere on the board
HDMI_CK+: Module1.188 (HDMI0_CLK_P); also elsewhere on the board
HDMI_CK-: Module1.190 (HDMI0_CLK_N); also elsewhere on the board
HDMI_D0+: Module1.182 (HDMI0_TX0_P); also elsewhere on the board
HDMI_D0-: Module1.184 (HDMI0_TX0_N); also elsewhere on the board
HDMI_D1+: Module1.176 (HDMI0_TX1_P); also elsewhere on the board
HDMI_D1-: Module1.178 (HDMI0_TX1_N); also elsewhere on the board
HDMI_D2+: Module1.170 (HDMI0_TX2_P); also elsewhere on the board
HDMI_D2-: Module1.172 (HDMI0_TX2_N); also elsewhere on the board
HDMI_HEAC-: Module1.153 (HDMI0_HOTPLUG); also elsewhere on the board
HDMI_SCL: Module1.200 (HDMI0_SCL); also elsewhere on the board
HDMI_SDA: Module1.199 (HDMI0_SDA); also elsewhere on the board
LED_ACTIVITY: Module1.21 (PI_nLED_Activity); also elsewhere on the board
unnamed: Module1.57 (SD_CLK), R11.2
unnamed: Module1.62 (SD_CMD), R16.1
unnamed: Module1.63 (SD_DAT0), R13.2
unnamed: Module1.67 (SD_DAT1), R14.2
unnamed: Module1.69 (SD_DAT2), R15.2
unnamed: Module1.61 (SD_DAT3), R12.2
SD_CLK: R11.1; also elsewhere on the board
SD_CMD: R16.2; also elsewhere on the board
SD_DAT0: R13.1; also elsewhere on the board
SD_DAT1: R14.1; also elsewhere on the board
SD_DAT2: R15.1; also elsewhere on the board
SD_DAT3: R12.1; also elsewhere on the board
USB_D+: Module1.105 (USB2_P); also elsewhere on the board
USB_D-: Module1.103 (USB2_N); also elsewhere on the board
VCC: Module1.77 (+5v_(Input)), Module1.79 (+5v_(Input)), Module1.81 (+5v_(Input)), Module1.83 (+5v_(Input)), Module1.85 (+5v_(Input)), Module1.87 (+5v_(Input)); also elsewhere on the board

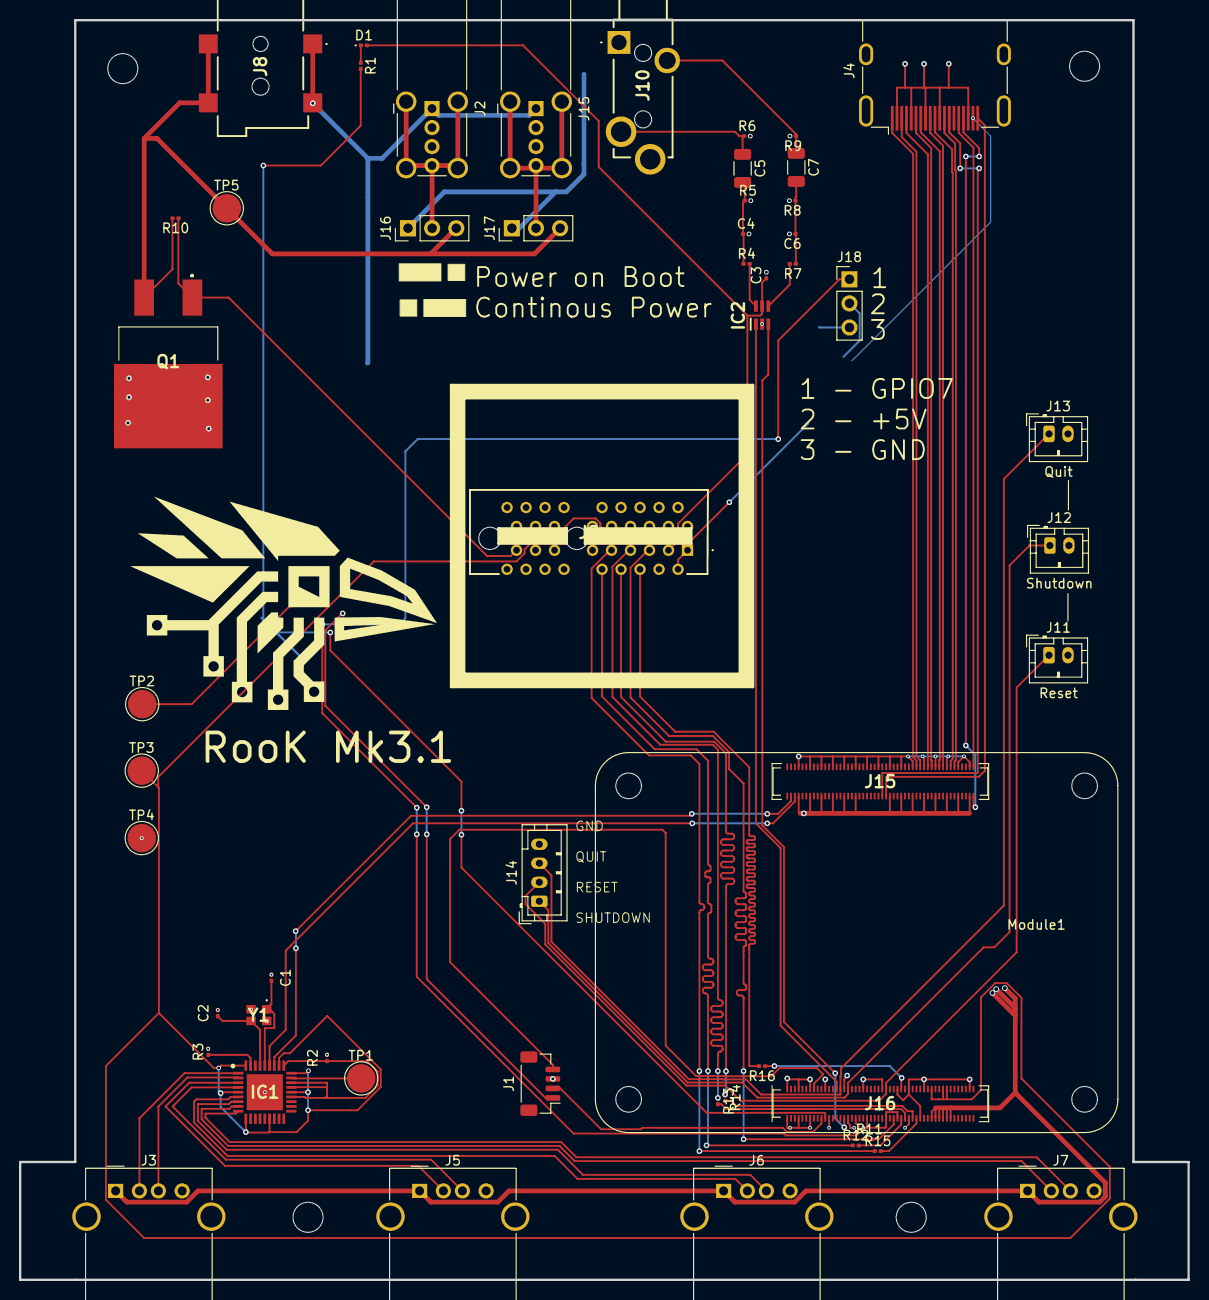
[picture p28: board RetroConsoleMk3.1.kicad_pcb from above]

Board: 2 copper layers, 123.0 x 132.6 mm, 54 parts (0 on the bottom side), 62 nets.

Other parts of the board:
J15#2, J16#2: DF40C100DS04V51

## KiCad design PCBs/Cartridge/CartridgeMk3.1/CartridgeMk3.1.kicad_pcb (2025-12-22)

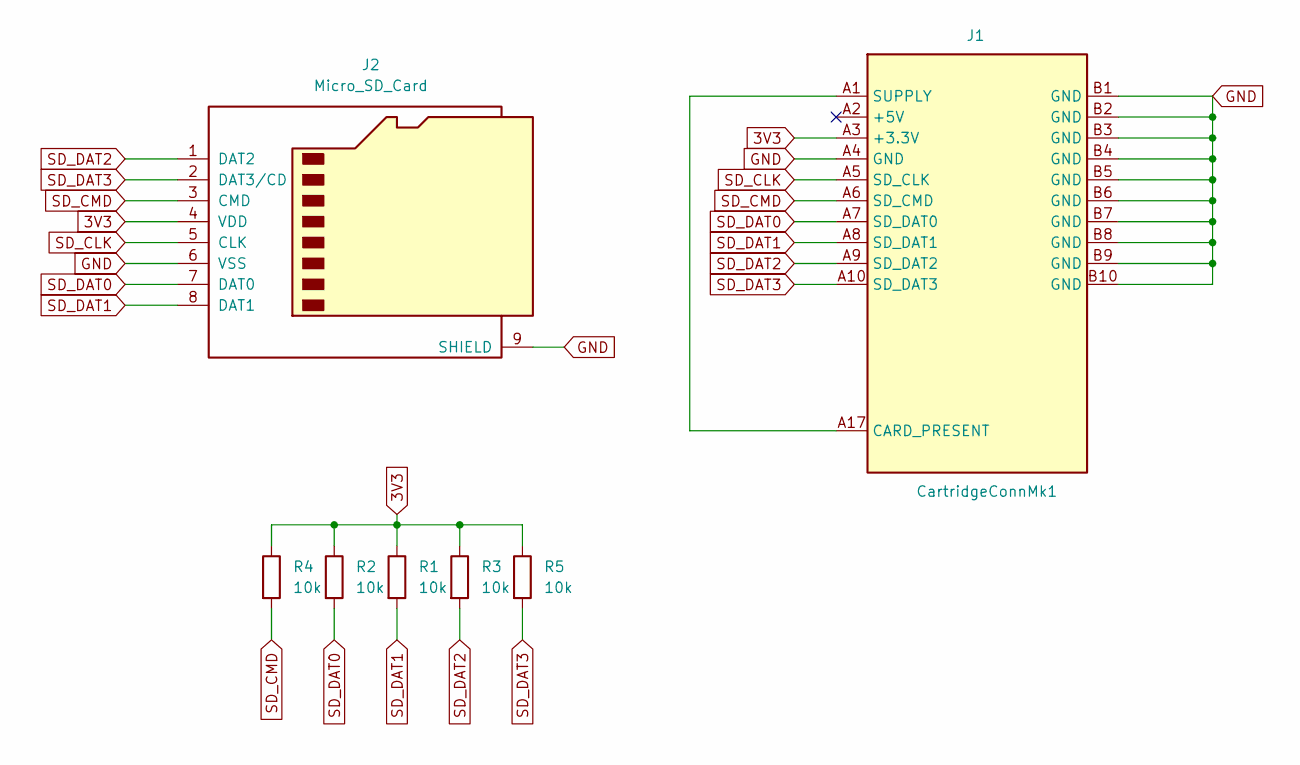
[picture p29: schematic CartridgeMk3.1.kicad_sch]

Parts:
J1: CartridgeConnMk1; BUS_PCIexpress_x1
J2: Micro_SD_Card; SDCARD_MOLEX_503398-1892
R1, R2, R3, R4, R5: 10k; R_0201_0603Metric

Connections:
3V3: J1.A3 (+3.3V), J2.4 (VDD), R1.1, R2.1, R3.1, R4.1, R5.1
GND: J1.A4 (GND), J1.B1 (GND), J1.B2 (GND), J1.B3 (GND), J1.B4 (GND), J1.B5 (GND), J1.B6 (GND), J1.B7 (GND), J1.B8 (GND), J1.B9 (GND), J1.B10 (GND), J2.6 (VSS), J2.9 (SHIELD)
unnamed: J1.A1 (SUPPLY), J1.A17 (CARD_PRESENT)
SD_CLK: J1.A5 (SD_CLK), J2.5 (CLK)
SD_CMD: J1.A6 (SD_CMD), J2.3 (CMD), R4.2
SD_DAT0: J1.A7 (SD_DAT0), J2.7 (DAT0), R2.2
SD_DAT1: J1.A8 (SD_DAT1), J2.8 (DAT1), R1.2
SD_DAT2: J1.A9 (SD_DAT2), J2.1 (DAT2), R3.2
SD_DAT3: J1.A10 (SD_DAT3), J2.2 (DAT3/CD), R5.2

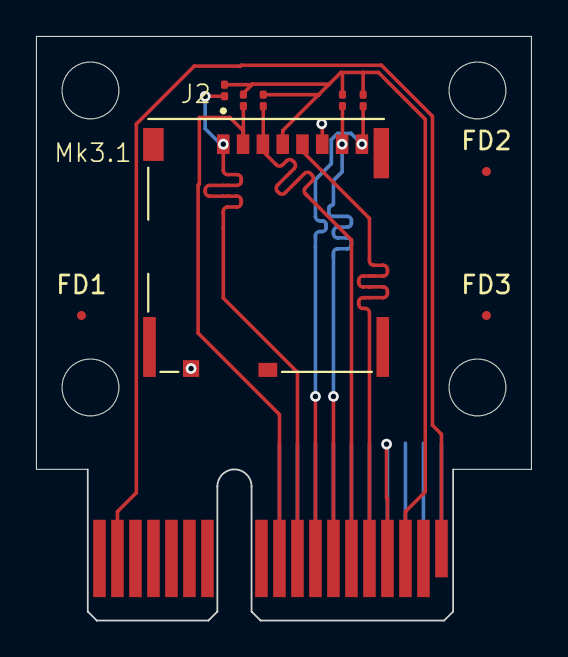
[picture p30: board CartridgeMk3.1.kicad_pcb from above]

Board: 2 copper layers, 27.5 x 32.5 mm, 10 parts (1 on the bottom side), 9 nets.

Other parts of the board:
FD1, FD2, FD3: Fiducial_0.5mm_Mask1.5mm

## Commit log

2025-09-27 updated button pieces
    [LegoCase_Konnexus_Mk1-Quit Button fat Border.stl]
2025-12-22 Updated Repo with files for Mk3.1 content
    [BackPanel.stl, Base.stl, Cartridge.kicad_sch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]
2025-12-25 updated backpanel
    [BackPanel.stl, BackPanel_Inlay.stl]
2026-01-23 added the Lifeline PCB
    [MainBoardMk3.1_KeepAliveMk3-B_Cu.gbr, MainBoardMk3.1_KeepAliveMk3-B_Mask.gbr, MainBoardMk3.1_KeepAliveMk3-B_Paste.gbr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]
2026-01-30 added STL file for BackPanel with Antenna hole.
    [BackPanel.stl]
2026-03-29 added a different back panel with internal holding of the antenna
    [BackPanel_internal_antenna.stl]
